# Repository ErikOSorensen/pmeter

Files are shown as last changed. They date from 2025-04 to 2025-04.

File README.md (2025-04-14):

# pmeter
RF power meter (AD8307 based) -- software to run on Raspberry Pi.

The power meter has a separate module with the sensor, and the plan is
to use an ADS1115, attached to a Raspberry Pi pico by i2c to sense the
voltage emitted (which will be more or less an affine function of the
power applied at the sensor. According to the [Analog Devices
datasheet](http://www.analog.com/media/en/technical-documentation/data-sheets/AD8307.pdf)
it should be possible to get decent performance from -75dBm to +17dBm
in the range from DC to 500MHz, but -70 to +10 dBm from DC to 150 MHz should
be achievable. There is a ADS1115 micropython library here: https://github.com/robert-hh/ads1x15

I want a controller housing with ports for two sensor heads. The sensor heads
will be built into aluminium diecast enclosure with RF connectors on one end and
a 4-wire cable to the controller unit: 1) power, 2) GND, 3) output voltage from
sensor, and 4) a voltage that signals which sensor head this is to the controller.

I want a raspberry pi pico with a wiznet 5500 ethernet controller, such that I
can use a REST interface to fetch readings if I like to. I also want an
interactive use. For interactive use I need to 1) be able to set the frequency
(calibrarion constants), offsets, and maybe the display units (from dBm to
Volts?). A rotary controller with a  button should be enough to step through
four modes: Channel A frequency, A offset, A units, B frequency, B offset, B
units. Then a display: Two lines of a 16x2 LCD display should in principle be
enough. Alternative: One 0.96 inch display for each channel (these are i2c). I
probably also should be able to display the ip-address of the controller (if
any).

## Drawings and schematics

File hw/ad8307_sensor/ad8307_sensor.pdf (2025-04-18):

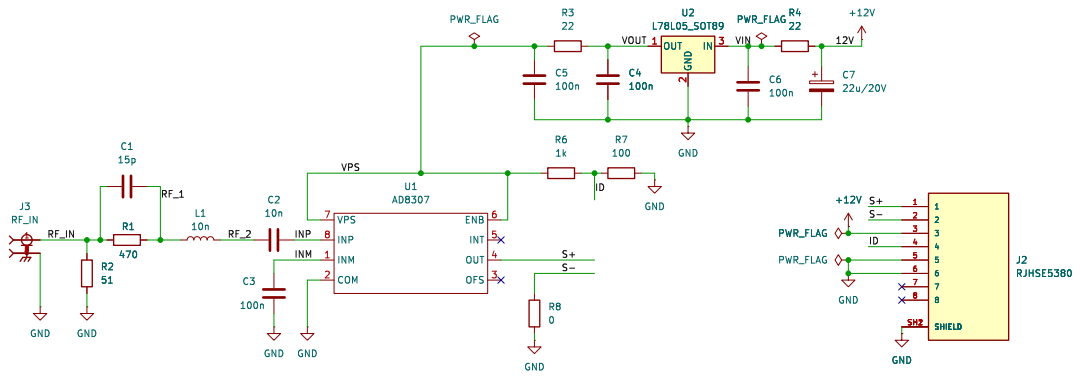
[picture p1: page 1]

Id: 1/1 Title: File: ad8307_sensor.kicad_sch Sheet: / C2

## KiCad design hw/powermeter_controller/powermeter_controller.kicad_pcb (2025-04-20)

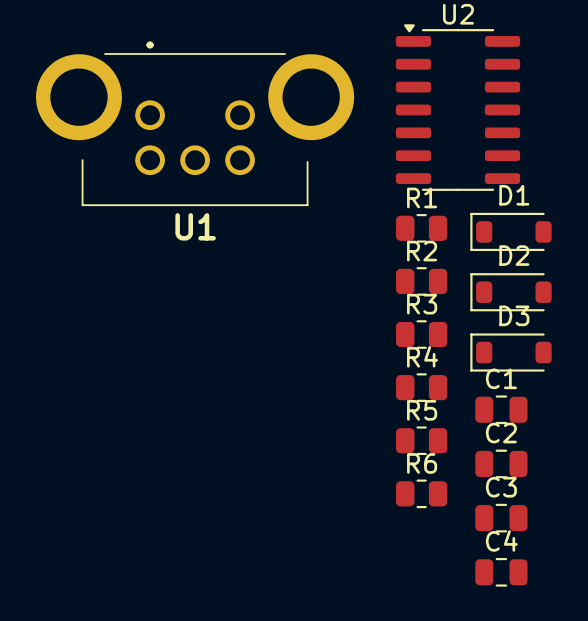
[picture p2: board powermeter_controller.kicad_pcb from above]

Board: 2 copper layers, 15 parts (0 on the bottom side), 8 nets, no tracks yet.

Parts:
C1, C2, C3, C4: 100n; C_0805_2012Metric
D1, D2, D3: 1n4148; D_SOD-123
R1, R2, R3: 18k; R_0805_2012Metric
R4, R5, R6: 82k; R_0805_2012Metric
U1: PEC12R-2217F-S0024; PEC12R2217FS0024
U2: 74HC14; SOIC-14_3.9x8.7mm_P1.27mm

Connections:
+3.3V: C4.2, R4.2, R5.2, R6.1, U2.14 (VCC)
GND: C1.2, C2.2, C3.2, C4.1, U1.2, U1.C1 (COMMON), U1.MH1, U1.MH2, U2.7 (GND)
unnamed: D1.2 (A), R1.2, R6.2, U1.1
unnamed: C1.1, D1.1 (K), R1.1, U2.1
unnamed: D2.2 (A), R2.1, R5.1, U1.A1 (CHANNEL_A)
unnamed: C2.1, D2.1 (K), R2.2, U2.3
unnamed: D3.2 (A), R3.1, R4.1, U1.B1 (CHANNEL_B)
unnamed: C3.1, D3.1 (K), R3.2, U2.5

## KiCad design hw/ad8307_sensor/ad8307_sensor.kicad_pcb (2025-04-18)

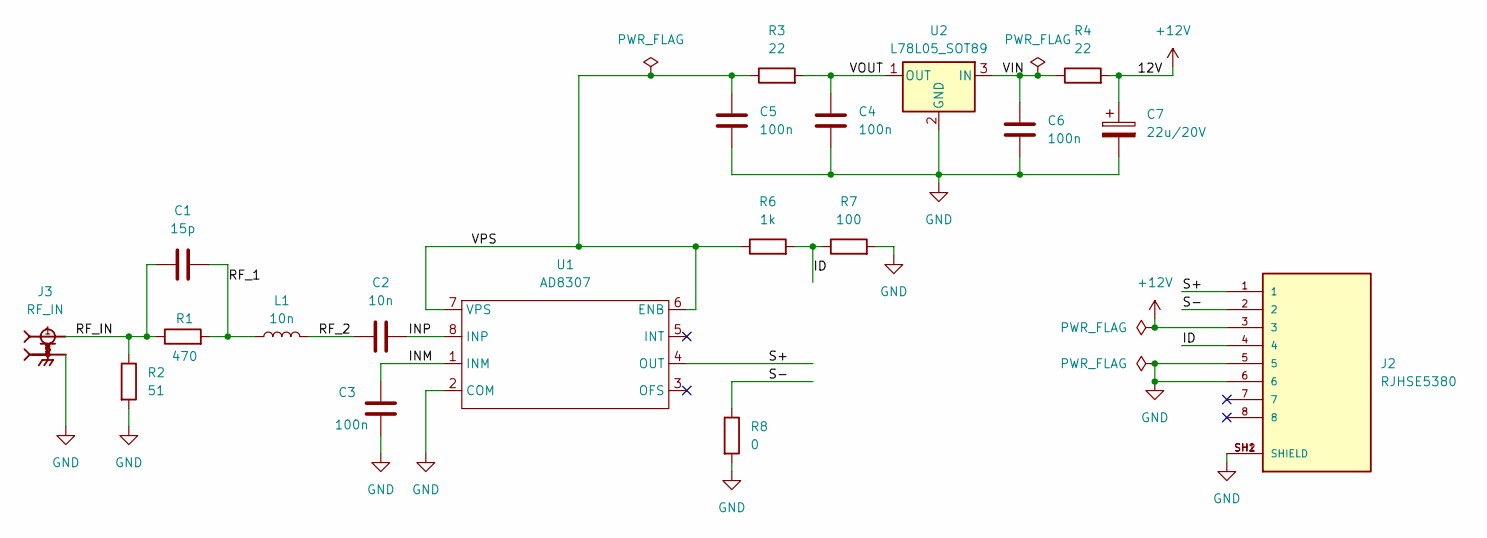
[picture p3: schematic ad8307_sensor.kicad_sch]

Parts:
C1: 15p; C_0603_1608Metric
C2: 10n; C_0603_1608Metric
C3: 100n; C_0603_1608Metric
C4, C5, C6: 100n; C_0805_2012Metric
C7: 22u/20V; CP_EIA-3528-21_Kemet-B
J2: RJHSE5380; AMPHENOL_RJHSE5380; PARTREV B
J3: RF_IN; SAMTEC_SMA-J-P-X-RA-TH1; PARTREV K
L1: 10n; L_0603_1608Metric
R1: 470; R_0603_1608Metric
R2: 51; R_0603_1608Metric
R3, R4: 22; R_0805_2012Metric
R6: 1k; R_0805_2012Metric
R7: 100; R_0805_2012Metric
R8: 0; R_0805_2012Metric
U1: AD8307; SOIC-8_3.9x4.9mm_P1.27mm
U2: L78L05_SOT89; SOT-89-3

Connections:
+12V: C7.1, J2.3, R4.2
/ID: J2.4, R6.2, R7.1
/INM: C3.1, U1.1 (INM)
/INP: C2.2, U1.8 (INP)
/RF_1: C1.2, L1.1, R1.2
/RF_2: C2.1, L1.2
/RF_IN: C1.1, J3.1, R1.1, R2.1
/S+: J2.1, U1.4 (OUT)
/S-: J2.2, R8.1
/VIN: C6.1, R4.1, U2.3 (IN)
/VOUT: C4.1, R3.2, U2.1 (OUT)
/VPS: C5.1, R3.1, R6.1, U1.6 (ENB), U1.7 (VPS)
GND: C3.2, C4.2, C5.2, C6.2, C7.2, J2.5, J2.6, J2.SH1 (SHIELD), J2.SH2 (SHIELD), J3.2, J3.3, J3.4, J3.5, R2.2, R7.2, R8.2, U1.2 (COM), U2.2 (GND)

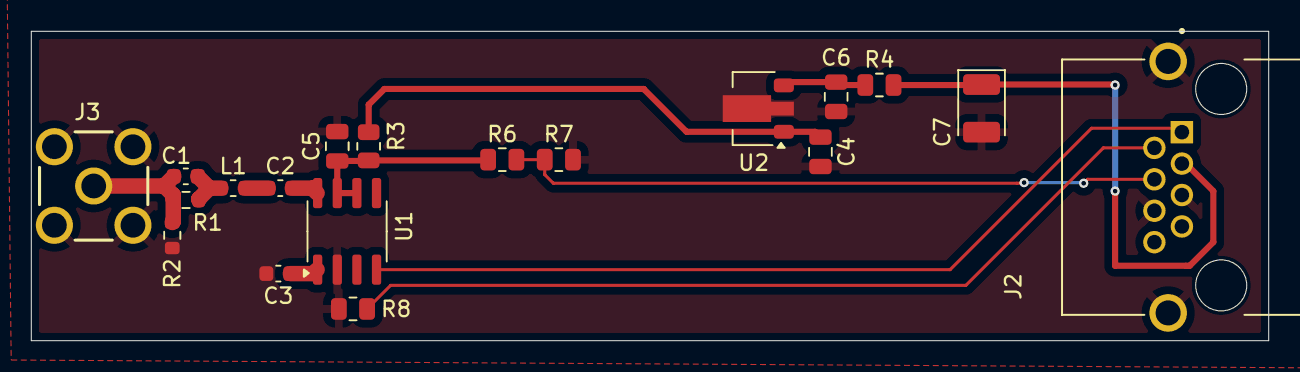
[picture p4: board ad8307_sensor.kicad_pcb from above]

Board: 2 copper layers, 80.0 x 20.0 mm, 19 parts (0 on the bottom side), 13 nets.

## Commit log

2025-04-18 Laying out a sensor to fit in a 80x25x25mm box with RJ45 connection to the controller box.
    [ad8307_sensor.kicad_pcb, ad8307_sensor.kicad_sch]
2025-04-20 Starting schematics of controller.
    [powermeter_controller.kicad_pcb, powermeter_controller.kicad_sch]
